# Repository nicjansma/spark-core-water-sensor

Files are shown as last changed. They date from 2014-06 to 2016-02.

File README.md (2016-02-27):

# Particle (Spark) Core / Photon / Electron Water Sensor

By [Nic Jansma](http://nicj.net)

This is an internet-connected water sensor that will alert you via SMS (or any other webhook via [IFTTT](https://ifttt.com)) if water is sensed.

I am currently using this near my sump-pump to alert me if the pump fails.  It can be run from either AC or battery power. 

## Hardware

For hardware, I'm utilizing a [Spark Core](https://www.spark.io) hooked up to a [Grove Water Sensor](http://www.seeedstudio.com/wiki/Grove_-_Water_Sensor).

Nowadays, there are even cheaper options from Particle (formerly Spark), such as the [Photon](https://store.particle.io) or [Electron](https://store.particle.io).

The Grove Water Sensor's three wires (power, ground and data) are soldered to the top of the device.

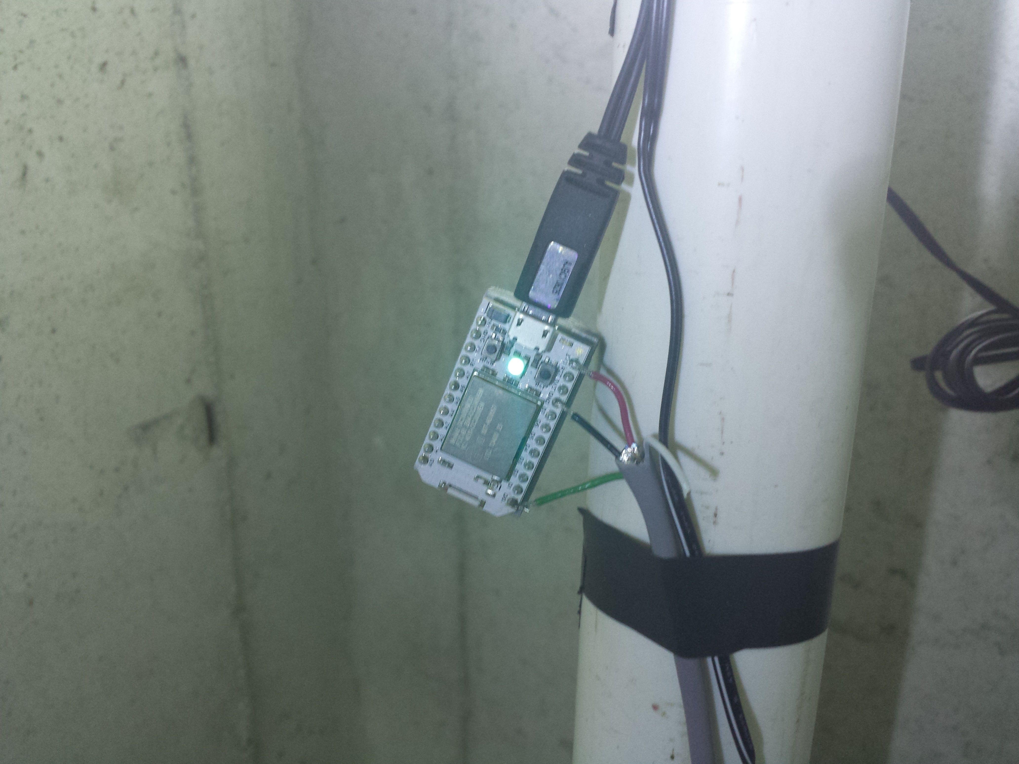
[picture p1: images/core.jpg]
Spark Core
  

I've 3D printed a simple "seat" for the Core to sit on so the external pins don't short.  The STL is included under `case/`.

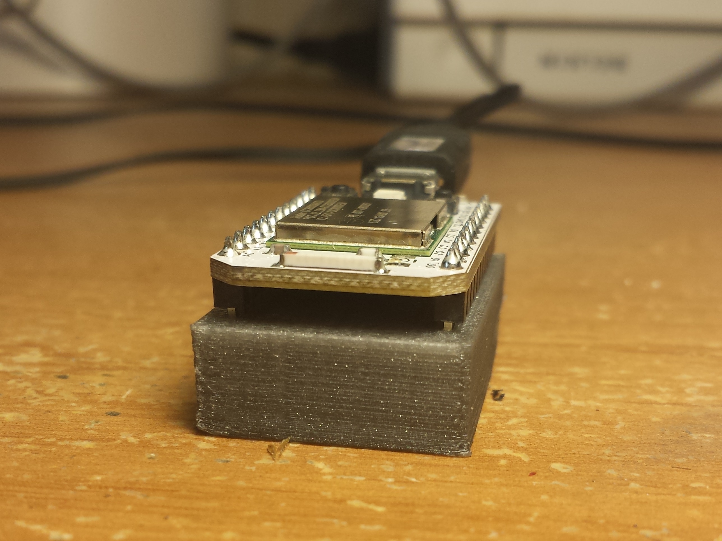
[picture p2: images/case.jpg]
Spark Core Case
  

The Core is taped to my sump pump's pipe, and the Water Sensor is taped just below ground-level in the sump pump water pit.

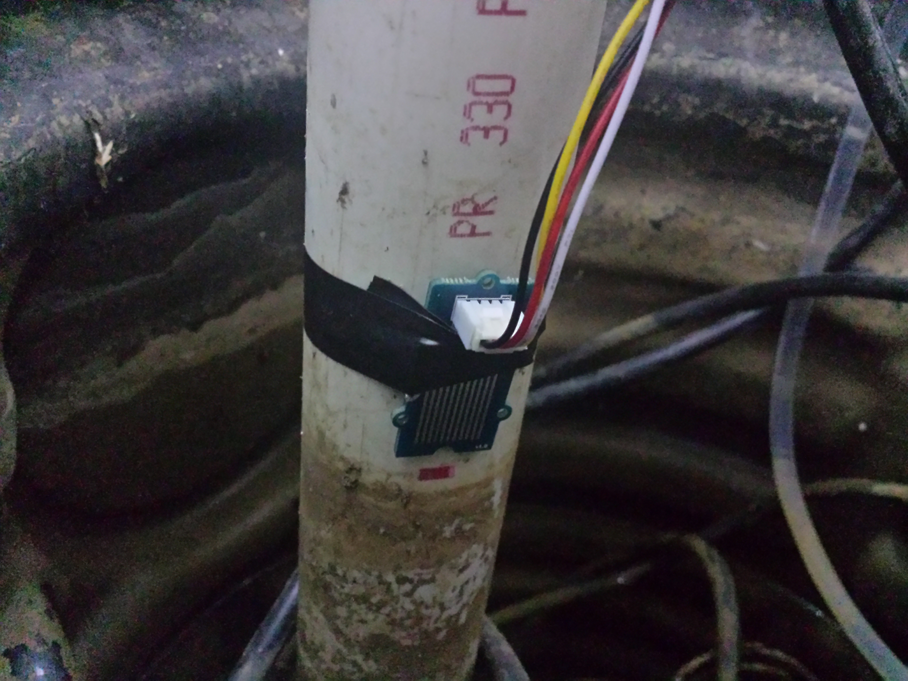
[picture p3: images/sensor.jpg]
Grove Water Sensor
  

## Firmware

The Spark Core firmware is available under `firmware/`.  It should work for a Photon or Electron as well.

The firmware publishes these two events to the [Spark Cloud](http://docs.spark.io/api/):

* `online` when the device first starts up
* `water_alarm` when water is sensed.  The payload is either `on` or `off`.

The firmware also exposes two variables:

* `alarmStatus`: `0` means not in alarm state, and `1` means the alarm is active.
* `water`: `0` means no water detected, and `1` means water detected.

### With Temperature + Humidity Sensor

In addition, there's also a version of the firmware available that's a combination Water Sensor plus a Temperature and Humidity logger, based on the [dht-logger](github.com/nicjansma/dht-logger) project.  To use this combination sensor, check out the `firmware-with-dht/` folder.

## Software

The [previous version](https://github.com/nicjansma/spark-core-water-sensor/releases/tag/v1.0.0) of this sensor used a NodeJS app to monitor for events from the Spark Core.  This app would then use the [Twilio](http://twilio.com/) API to send me a SMS when there was an alarm.

Particle now offers [Webhooks](https://docs.particle.io/guide/tools-and-features/webhooks/), which does this job for you.  You don't have to run a NodeJS app.  Once it senses an event from your Spark Core / Photon / Electron, it will publish an event to any web URL you specify.

Instead of using Twilio for SMS, I am now using [IFTTT](https://ifttt.com) to send me an email, SMS and a [Pushbullet](http://pushbullet.com) notification all at once -- for free!

The creation of the Particle Webhook is pretty simple. First, [install](https://docs.particle.io/guide/tools-and-features/cli/) the `particle-cli` NPM module:

``` 
npm install -g particle-cli
```

Then, make sure you're logged in:

``` 
particle login
```

Next, create an [IFTTT](https://ifttt.com) account.  Then, create a [IFTTT Maker](https://ifttt.com/maker) page.  On there, look for your private key (under _Your key is_).

Then, create a file called `ifttt.json` into your directory (see the sample in this repo).  Replace `[your maker key]` in that file with your private key.  It should look something like this:

``` 
{
    "eventName" : "water_alarm",
    "url" : "https://maker.ifttt.com/trigger/alert/with/key/[your maker key]",
    "requestType" : "POST",
    "query" : {
        "value1" : "Water Alarm",
        "value2" : "{{SPARK_EVENT_VALUE}}"
    },
    "mydevices" : true
}
```

Last, you need to tell Particle how to integrate with IFTTT.  Do this:

``` 
particle webhook create ifttt.json
```

You should see a success message.  You're all set!

## SmartThings

This device can be hooked up to a [SmartThings](https://www.smartthings.com/) hub.

See my [smart-things project](https://github.com/nicjansma/smart-things/tree/master/devicetypes/nicjansma/spark-core-water-sensor) for a sample Device Handler.

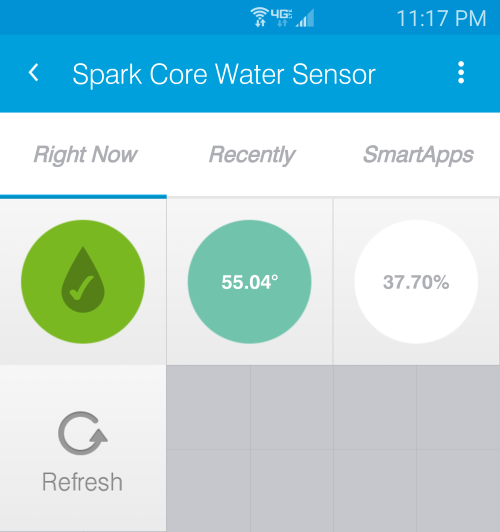
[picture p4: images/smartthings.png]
SmartThings
  

## Parts and Cost

Total cost is around $21.90:

* $19 for the [Photon](https://store.particle.io)
* $2.90 for the [Grove Water Sensor](http://www.seeedstudio.com/wiki/Grove_-_Water_Sensor)
* Cables to connect the Water Sensor to the Core

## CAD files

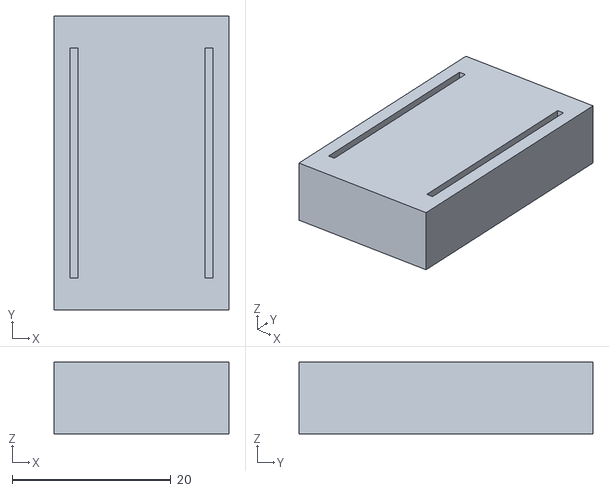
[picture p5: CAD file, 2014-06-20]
case/seat.stl
22.0 x 37.0 x 9.00

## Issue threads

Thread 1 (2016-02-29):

False positives

Connor-Knabe, 2016-02-29:
Have you ever had a false positive with this setup?  I have mine setup near a pool pump and twice it has gone off (falsely) about 10 minutes after the pool pump flips on.  They both are using the same outlet. Maybe the pump is drawing too much power which takes some away from the Photon?

Also have you attempted to hook multiple water sensors into the photon like wiring 3 of them to the same pins?

nicjansma, 2016-03-01:
Hi Connor,

I haven't had any false positives so far, but I'm also using it indoors.  Is it possible that outdoor humidity around the pool is shorting the sensor somehow?  Are you using the Grove Water Sensor like I am?  It's also quite possible the power draw is affecting it.  Maybe put it on a different outlet, or temporarily on battery power to diagnose if that's the issue?

I don't think having all sensors all on the same digital pin would work, but you could easily power all of the sensors with 3.3v and Ground, and have each sensors's output on one of the remaining 6 digital pins.  The `isExposedToWater` function could be pretty easily updated to read all 6 pins.

Connor-Knabe, 2016-03-01:
Yep I'm using the Grove Water Sensor also.  I'll attempt it on a new outlet and see if it fixes things. Thanks!

Connor-Knabe, 2016-03-19:
This seemed to fix the issue. :+1:

Closed 2016-03-19.

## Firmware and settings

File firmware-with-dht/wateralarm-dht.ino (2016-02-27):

//
// Particle (Spark) Core/Photon/Electron Water Alarm + Temperature/Humidity Logger
// By Nic Jansma
// http://nicj.net
//
// This is a combination of a Water Alarm (http://github.com/nicjansma/spark-water-alarm)
// and a DHT temperature/humidity sensor (http://github.com/nicjansma/dht-logger)
//

//
// Includes
//
#include "application.h"
#include "DHT.h"
#include "Adafruit_IO_Client.h"
#include "Adafruit_IO_Arduino.h"

//
// Configuration
//

// pins
#define WATER_SENSOR D0
#define DHT_SENSOR D3
#define LED D7

// How long to wait before noting that the alarm has switched states -- this
// helps stop a super-sensitive sensor from ping-ponging back and forth a lot.
#define DEBOUNCE_SECONDS 300

// device name
#define DEVICE_NAME "wateralarm"

// sensor type: [DHT11, DHT22, DHT21, AM2301]
#define DHTTYPE DHT22

// whether to use Farenheit instead of Celsius
#define USE_FARENHEIT 1

// min/max values (sanity checks)
#define MIN_TEMPERATURE -30
#define MAX_TEMPERATURE 120

#define MIN_HUMIDITY 0
#define MAX_HUMIDITY 100

// temperature/humidity sensor sending interval (seconds)
#define SEND_INTERVAL 60

// AdaFruit integration
#define ADAFRUIT_API_KEY "27df87804133673ce466a5f90334cf11affeaf2d"
#define ADAFRUIT_FEED_TEMPERATURE "wateralarm-temp"
#define ADAFRUIT_FEED_HUMIDITY "wateralarm-humidity"
#define ADAFRUIT_FEED_HEAT_INDEX "wateralarm-heat-index"

// Particle event
#define PARTICLE_LOG_EVENT_NAME "iot-log"

//
// Vars
//

// whether or not water is sensed: 0 = no, 1 = yes
int water = 0;

// the alarm state: 0 = off, 1 = on
int alarmState = 1;

// the last time we switched alarm states (ms since Unix epoch)
int lastStateSwitchTime = 0;

// TCP client
TCPClient tcpClient;

// DHT sensor object
DHT dht(DHT_SENSOR, DHTTYPE);

// current values
float humidity;
float temperature;
float heatIndex;

char humidityString[10];
char temperatureString[10];
char heatIndexString[10];

// last time since we sent sensor readings
int lastUpdate = 0;

// Adafruit feeds
Adafruit_IO_Client aio = Adafruit_IO_Client(tcpClient, ADAFRUIT_API_KEY);
Adafruit_IO_Feed aioFeedTemperature = aio.getFeed(ADAFRUIT_FEED_TEMPERATURE);
Adafruit_IO_Feed aioFeedHumidity = aio.getFeed(ADAFRUIT_FEED_HUMIDITY);
Adafruit_IO_Feed aioFeedHeatIndex = aio.getFeed(ADAFRUIT_FEED_HEAT_INDEX);

// for Particle.publish payloads
char payload[1024];

//
// Functions
//

// Spark setup
void setup() {
    // initialize our pins I/O
    pinMode(LED, OUTPUT);
    pinMode(WATER_SENSOR, INPUT);

    // tell the world we're online
    Particle.publish("online");

    // publish the water variable
    Particle.variable("water", &water, INT);

    // publish the alarm state variable
    Particle.variable("alarmState", &alarmState, INT);

    // temp/humidity vars
    Particle.variable("temperature", &temperatureString[0], STRING);
    Particle.variable("humidity", &humidityString[0], STRING);
    Particle.variable("heatIndex", &heatIndexString[0], STRING);
    
    // start the DHT and Adafruit logging
    dht.begin();
    aio.begin();

    // startup event
    sprintf(payload,
            "{\"device\":\"%s\",\"state\":\"starting\"}",
            DEVICE_NAME);

    Particle.publish(PARTICLE_LOG_EVENT_NAME, payload, 60, PRIVATE);
}

// Spark loop
void loop() {
    checkWater();
    checkDHT();
}

void checkWater() {
    water = isExposedToWater();

    if (water) {
        digitalWrite(LED, HIGH);

        //
        // Alarm ON
        //
        if (alarmState == 0) {
            // only alarm if we're past the debounce interval
            int now = Time.now();
            if (now - lastStateSwitchTime > DEBOUNCE_SECONDS) {
                alarmState = 1;
                lastStateSwitchTime = now;
                Particle.publish("water_alarm", "on", 60, PRIVATE);

                // startup event
                sprintf(payload,
                        "{\"device\":\"%s\",\"state\":\"on\"}",
                        DEVICE_NAME);

                Particle.publish(PARTICLE_LOG_EVENT_NAME, payload, 60, PRIVATE);
            }
        }
    } else {
        digitalWrite(LED, LOW);

        //
        // Alarm off
        //
        if (alarmState == 1) {
            // only alarm if we're past the debounce interval
            int now = Time.now();
            if (now - lastStateSwitchTime > DEBOUNCE_SECONDS) {
                alarmState = 0;
                lastStateSwitchTime = now;
                Particle.publish("water_alarm", "off", 60, PRIVATE);

                // startup event
                sprintf(payload,
                        "{\"device\":\"%s\",\"state\":\"off\"}",
                        DEVICE_NAME);

                Particle.publish(PARTICLE_LOG_EVENT_NAME, payload, 60, PRIVATE);
            }
        }
    }
}

void checkDHT() {
    int now = Time.now();

    // only run every SEND_INTERVAL seconds
    if (now - lastUpdate < SEND_INTERVAL) {
        return;
    }

    lastUpdate = now;

    // read humidity and temperature values
    humidity = dht.readHumidity();
    temperature = dht.readTemperature(USE_FARENHEIT);

    if (temperature == NAN
        || humidity == NAN
        || temperature > MAX_TEMPERATURE
        || temperature < MIN_TEMPERATURE
        || humidity > MAX_HUMIDITY
        || humidity < MIN_HUMIDITY) {
        // if any sensor failed, bail on updates
        return;
    }

    // calculate the heat index
    heatIndex = dht.computeHeatIndex(temperature, humidity, USE_FARENHEIT);

    // convert floats to strings for Particle variables
    sprintf(temperatureString, "%.2f", temperature);
    sprintf(humidityString, "%.2f", humidity);
    sprintf(heatIndexString, "%.2f", heatIndex);

    aioFeedTemperature.send(temperature);
    aioFeedHumidity.send(humidity);
    aioFeedHeatIndex.send(heatIndex);

    sprintf(payload,
        "{\"device\":\"%s\",\"temperature\":%.2f,\"humidity\":%.2f,\"heatIndex\":%.2f}",
        DEVICE_NAME,
        temperature,
        humidity,
        heatIndex);

    Particle.publish(PARTICLE_LOG_EVENT_NAME, payload, 60, PRIVATE);
}

// determine if we're exposed to water or not
boolean isExposedToWater() {
    if (digitalRead(WATER_SENSOR) == LOW) {
        return true;
    } else {
        return false;
    }
}
